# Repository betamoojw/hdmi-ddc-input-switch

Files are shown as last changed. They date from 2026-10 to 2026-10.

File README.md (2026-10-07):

# HDMI-DDC Input Switch

A small desk box with mechanical keys that switches your monitor's input in one press.
It plugs into a spare HDMI port on the monitor and sends the monitor's own "change input"
command over DDC/CI, so it works with whatever is on the other inputs: a PC on
DisplayPort, a laptop on USB-C, a console on HDMI. Nothing to install on any computer.

**Project page: <https://jeyeager65.github.io/hdmi-ddc-input-switch/>**: build guide,
configurator and firmware installer.

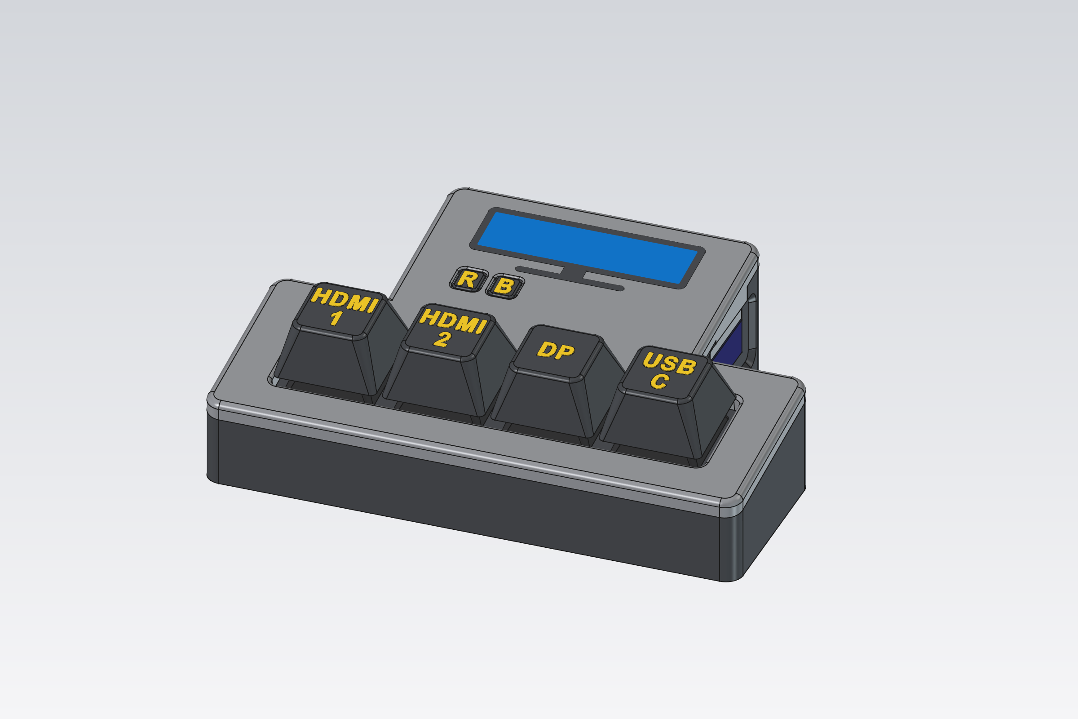
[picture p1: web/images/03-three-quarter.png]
The switch


- **[Adafruit Feather RP2040 DVI](https://www.adafruit.com/product/5710)** inside; keys are
  standard MX switches (built with [Kailh Tactile Brown](https://www.adafruit.com/product/4954)).
- **Any DDC/CI monitor** via presets. Includes LG UltraGear, which needs LG's
  proprietary command (tested on the 45GR75DC-B), and the standard MCCS command.
- **Info screen:** pressing the key for the switch's own HDMI port shows the current
  setup on the monitor.
- **Set up in the browser:** a web page (Chrome/Edge, Web Serial) installs firmware
  and configures the keys. Settings live on the switch.
- **3D-printed case** designed to print without supports, with multi-colour inlays.

## Build it

Everything for building and using it is on the
[project page](https://jeyeager65.github.io/hdmi-ddc-input-switch/): **parts list, print
files, wiring, assembly, monitor setup, configuration, firmware install and
troubleshooting**. You can also run the page locally (below). Firmware is attached to
each [release](https://github.com/jeyeager65/hdmi-ddc-input-switch/releases) too.

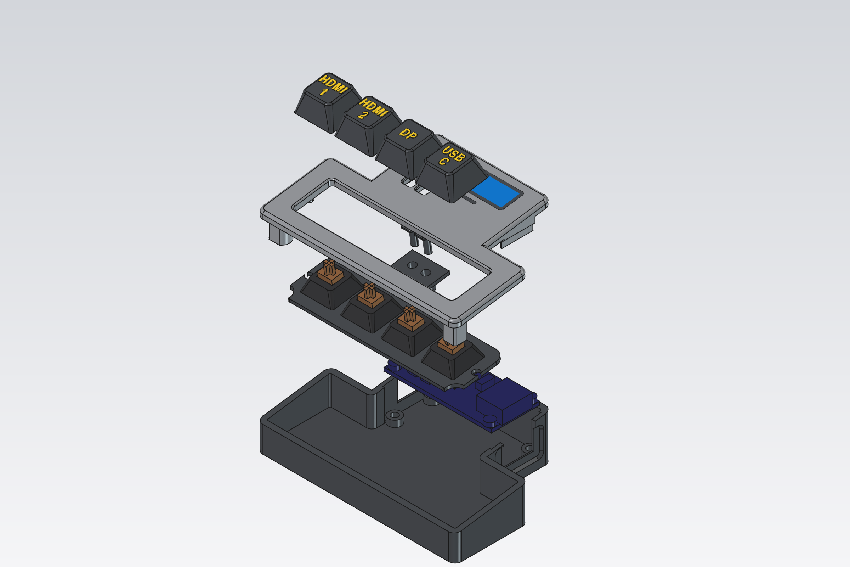
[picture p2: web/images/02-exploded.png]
Exploded view


## Repository layout

| Path | What |
|---|---|
| `src/` | Firmware (Arduino, earlephilhower RP2040 core): `config` (flash settings), `ddc` (DDC/CI), `buttons`, `protocol` (JSON over USB serial), `screen` (PicoDVI info screen), `app` |
| `web/` | The project page: guide, configurator and installer (`index.html`), monitor presets (`presets.json`), images |
| `case/` | Parametric FreeCAD scripts for the case (`case.py`), keycaps (`keycaps.py`), test prints (`coupon.py`), assembly preview (`assembly.py`), build-step scenes (`steps.py`), GUI preview colours (`show.py`), guide pictures (`render.py`) |
| `case/export/` | Print-ready STL / 3MF files |
| `tools/version.py` | Stamps the firmware version from the git tag |
| `tools/gfxfont.py` | Makes the info screen's bitmap fonts (see `src/fonts/`) |
| `tools/screenshot.py` | Saves the info screen as a PNG over USB serial (`python tools/screenshot.py COM11 out.png`) |
| `.github/workflows/firmware.yml` | CI: build; on tags, release + publish the page |
| `PLAN.md` | Design decisions, protocol, progress and test checklist |

## Firmware

Built with [PlatformIO](https://platformio.org/). The platform, core and libraries are
pinned in `platformio.ini`.

```sh
pio run -e feather_dvi          # build → .pio/build/feather_dvi/firmware.uf2
```

To flash, put the board in install mode (hold BOOT, tap RESET, or use the page's
Install tab) and copy `firmware.uf2` to the `RPI-RP2` drive. On Windows, `pio run -t
upload` needs a Zadig driver for picotool; copying the file doesn't.

Serial at 115200: one JSON object per line (`{"cmd":"version|get|set|save|send|raw|scan|reset|reboot|bootloader|screenshot"}`),
plus `1`–`8` / `s` / `?` shortcuts for bench testing. See `src/protocol.h` and `PLAN.md`.

## Web page, locally

Web Serial needs https or `localhost`:

```sh
cp .pio/build/feather_dvi/firmware.uf2 web/      # optional: for the Install tab
mkdir -p web/print && cp case/export/*.{stl,3mf} web/print/   # optional: guide downloads
python -m http.server 8000 -d web                # then open http://localhost:8000
```

## Case

The case is generated by Python scripts run inside FreeCAD 1.x, all dimensions as
parameters at the top of each file. Headless:

```sh
freecadcmd case/case.py        # tray, lid (+ inlays), switch plate, R/B buttons → case/export/
freecadcmd case/keycaps.py     # keycaps + stem-fit test
freecadcmd case/assembly.py    # assembly and exploded preview → case/build/
freecadcmd case/steps.py       # build-step scenes → case/build/
```

Then, in the FreeCAD GUI's Python console, `case/render.py` renders the README and guide
pictures into `web/images/`.

Board geometry comes from Adafruit's published PCB files; connector heights were
measured. The scripts check for collisions and overhangs as they go.

Things you may want to change (top of each file):

- `case.py`: `USB_PLUG` / `HDMI_PLUG`, your cables' plug housing sizes (they set the
  port recesses and the case height); `NUM_KEYS`; `TILT_DEG`; `LID_ART`.
- `keycaps.py`: `LEGENDS`, the text on each key, left to right (`
` for two lines).
- Print settings that the geometry assumes: 0.2 mm layers (inlays are 0.6 mm deep;
  `SACRIFICIAL_LAYER` bridges the screw holes), 0.4 mm nozzle.

## Adding a monitor

Find your monitor's values with the configurator's **Try** button, then add an entry to
`web/presets.json`:

```json
{ "id": "brand-model", "name": "Brand Model", "vcp": 96, "src": 81,
  "inputs": [{ "name": "DP", "value": 15 }, { "name": "HDMI 1", "value": 17 }],
  "notes": "What you tested it on." }
```

`vcp`/`src` are the input-select VCP code and DDC/CI source address (standard: `0x60`
from `0x51`). Pull requests welcome.

## Releases

Pushing a tag like `v1.0.0` builds the firmware, attaches it to a GitHub Release, and
publishes the project page (with that firmware and the print files) to GitHub Pages.
One-time setup: **Settings → Pages → Source: GitHub Actions**.

## License

MIT, see [LICENSE](LICENSE). That covers the firmware, the web page and the case and
keycap designs. The info screen's fonts are Noto Sans under the SIL Open Font
License (see `src/fonts/README.md`).

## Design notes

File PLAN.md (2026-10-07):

# hdmi-ddc-input-switch — Implementation Plan

Companion to [hdmi-ddc-input-switch-brief.md](hdmi-ddc-input-switch-brief.md). Where this plan and the brief disagree, **this plan wins** (see Decisions).

## Decisions

| # | Decision | Replaces in brief |
|---|---|---|
| D1 | **Runtime configuration**, stored in flash, edited from a web configurator over Web Serial. One firmware build for everyone. | Compile-time profile selection |
| D2 | Monitor "profiles" become **presets** in `web/presets.json`. Adding a monitor = adding a preset. | Profiles in C++ |
| D3 | Invalid config (a button pointing at an input that doesn't exist, bad pin) is **rejected**: the firmware refuses it and the web page blocks the save. | `static_assert` |
| D4 | **Always output video** on the Feather's HDMI port: a simple text info screen. Compile flag exists only to turn it *off* for debugging. | Conditional DVI keep-alive, "status page out of scope" |
| D5 | No special "Info" button. The info screen is just the input the Feather is plugged into (e.g. HDMI 2); the user maps a normal button to it and labels the keycap. No toggle-back. | — |
| D6 | **Button count is configurable** (1–8 in firmware, limited by free pins); the case is parametric in the same count. | Fixed 2–4 |
| D6a | Buttons have an **action**: switch input, send an arbitrary VCP set command (e.g. a brightness preset), or none. Lets a button whose input is unused (HDMI 1 today) do something else. The onboard **BOOT button is readable as GPIO7** (isolated by diode D3 per the schematic), so it can be an extra configurable button, reachable through a pinhole in the lid (e.g. long-press = factory reset). RESET (SW1) is hardwired to RUN and can't be repurposed. | "Brightness/contrast out of scope" (only as a generic VCP action; no dedicated UI) |
| D7 | No unit-test environment. Verification is on hardware via the serial protocol. | — |
| D8 | Install via **UF2 + web page** (1200-baud touch → BOOTSEL drive → save `.uf2`). No WebUSB/PICOBOOT for v1 (Windows driver issue). | — |
| D9 | Case designed in **FreeCAD 1.1** as a parametric Python script, driven via the `freecad` MCP server (`.mcp.json`). | — |

## Architecture

### Repository layout

```
platformio.ini
src/
  main.cpp          setup/loop: buttons, serial, screen refresh
  config.h/.cpp     Config struct, defaults, validate(), load/save (EEPROM emu + CRC)
  ddc.h/.cpp        buildPacket(), ddcSend(), scanBus()   (transport kept separate — see Future)
  buttons.h/.cpp    debounce, edge detect
  protocol.h/.cpp   JSON-lines + single-char bench commands
  screen.h/.cpp     PicoDVI text-mode info screen (#ifndef DISABLE_VIDEO)
web/
  index.html        Install + Configure tabs (static, GitHub Pages)
  presets.json      monitor presets
case/
  case.py           parametric FreeCAD script (source of truth)
  export/           generated STL/3MF (built from case.py)
.github/workflows/
  build.yml         build .uf2 on push; attach to Release on tag
  pages.yml         deploy web/ (+ latest .uf2) to GitHub Pages
```

### Config model (firmware)

```cpp
struct InputDef  { char name[12]; uint8_t value; };
enum class Action : uint8_t { None, Input, Vcp };
struct ButtonDef {
  uint8_t pin;
  Action  action;
  uint8_t inputIndex;             // Action::Input
  uint8_t vcpCode, vcpSrc;        // Action::Vcp — any VCP set, e.g. a brightness preset (0x10) or picture mode
  uint16_t vcpValue;
};

struct Config {
  uint16_t  magic, schema;        // schema bumps on layout change → defaults
  char      presetName[24];
  uint8_t   vcpCode;              // 0xF4 LG / 0x60 MCCS
  uint8_t   sourceAddr;           // 0x50 LG / 0x51 MCCS
  uint8_t   numInputs;  InputDef  inputs[8];
  uint8_t   selfInput;            // index of the input the Feather is plugged into (0xFF = unknown)
  uint8_t   numButtons; ButtonDef buttons[8];
  uint32_t  crc;
};
```

- **Defaults** (empty/corrupt flash or schema mismatch): LG UltraGear; inputs DP `0xD0`, USB-C `0xD1`, HDMI 1 `0x90`, HDMI 2 `0x91`; self = HDMI 2; buttons left to right (as on the printed keycaps) A0→HDMI 1, A1→HDMI 2, A2→DP, A3→USB-C.
- **validate()**: `numInputs ≤ 8`, `numButtons ≤ 8`, each `Action::Input` button's `inputIndex < numInputs`, each pin in the allowed list and unique, names non-empty.
- **Allowed pins** (from schematic): A0–A3 (GPIO26–29), D24, D25, D5, D6, D9, D10, D11, D12, D13 (has red LED + resistor; usable with pull-up, LED glows faintly), MISO/MOSI/SCK, RX/TX, and BOOT (GPIO7). Excluded: SDA/SCL (GPIO2/3, DDC), GPIO4 (NeoPixel), GPIO16–23 (DVI).
- **Storage**: earlephilhower `EEPROM` emulation (one flash sector). A flash write stalls both cores, so video will glitch on save — accepted, documented.
- **Factory reset**: hold the first two buttons at power-up (or `{"cmd":"reset"}`).
- Packet + checksum are generic: `[src, 0x84, 0x03, vcp, 0x00, value, xor(0x6E, …)]`. Known-good: LG DP → checksum `0x9D`; MCCS DP1 `0x0F` → `0xD7`.

### Serial protocol (115200, newline-terminated)

Lines starting with `{` are JSON (ArduinoJson); otherwise single-char bench commands.

| Request | Response |
|---|---|
| `{"cmd":"version"}` | `{"fw":"1.0.0","schema":1,"board":"feather_dvi"}` |
| `{"cmd":"get"}` | full config as JSON (`pin` as Feather labels like `"A0"`, `self` = input index or -1) |
| `{"cmd":"set","config":{…}}` | `{"ok":true}` or `{"ok":false,"error":"button 2: input 5 out of range"}` — applies to RAM only |
| `{"cmd":"save"}` | writes flash |
| `{"cmd":"send","input":2}` | `{"ok":true,"ack":true}` |
| `{"cmd":"raw","vcp":244,"src":80,"value":208}` | ack — for discovering values on new monitors |
| `{"cmd":"scan"}` | `{"devices":[55,80]}` |
| `{"cmd":"reset"}` / `{"cmd":"reboot"}` / `{"cmd":"bootloader"}` | |
| `1`–`8` `s` `?` | bench shortcuts: send input slot 1–8, scan, help (human-readable) |

Unsolicited events (button presses, boot scan) are emitted as `{"event":…}` lines so the web page can show live activity.

### Info screen

PicoDVI 1-bit graphics, 640×480 (`DVIGFX1`, `DVI_RES_640x480p60`), drawn with Adafruit GFX and Noto Sans bitmap fonts: title with a version pill, framed Keys / Monitor / Tips panels (a Last command panel would always show the switch's own input), the switch's own input highlighted, setup address and uptime in the footer (was 80-column text until 2026-10-06). Video only while the screen is in use (see Progress). Runs on core 1. Call `Wire.setClock(50000)` **after** video starts (PicoDVI changes the system clock).

```
 HDMI-DDC INPUT SWITCH  v1.0.0          Preset: LG UltraGear (VCP F4 / src 50)
 You are viewing HDMI 2 - the switch's own port.

 Buttons:  [1] DP   [2] USB-C   [3] HDMI 1   [4] HDMI 2
 DDC:      0x37 OK   EDID 0x50 OK
 Last:     USB-C (0xD1) ACK   12s ago
 Configure: https://jeyeager65.github.io/hdmi-ddc-input-switch/
```

### Web page

Single static page, Chrome/Edge only (Web Serial). No build step.

- **Install tab**: pick port → open at 1200 baud and close (core reboots to BOOTSEL) → fetch latest `.uf2` → `showSaveFilePicker` onto the `RPI-RP2` drive. Fallback text: hold BOOT, tap RESET, drag the file.
- **Configure tab**: connect → `version` (warn on schema mismatch) → `get` → form:
  - preset dropdown (from `presets.json`) or Custom: VCP code, source address
  - input table: name, value, **Try** button (`send`/`raw`), "this is the switch's own port" radio
  - button table: pin dropdown (allowed pins only), input dropdown; add/remove rows
  - client-side validation mirrors firmware → **Save** (`set` then `save`)
  - live event log
- **presets.json** entry: `{ "id", "name", "vcp", "src", "inputs":[{"name","value"}], "notes" }`. Ship `lg-ultragear` and `mccs-standard` (DP1 0x0F, DP2 0x10, HDMI1 0x11, HDMI2 0x12; USB-C omitted — vendor-specific, e.g. Dell 0x1B).

### Case (FreeCAD)

**Decided (2026-10-03):** board centred behind the key row, fully inside the walls; the back section's side walls are thinned to 1.6 mm and the overhanging receptacle shells poke into tight holes (+0.25 mm), so plugs seat within ~1 mm of full insertion; lid is a flat plate mounted at 8° (keys centred in the front section); prints without supports (one-layer bridge capping each screw counterbore, no foot recesses — bumpers stick to the flat bottom); heat-set inserts (M2.5 for the Feather, M3 for the lid: 2 screws up through the floor at the front, 2 through the back wall); switches in a separate flat plate glued under a window in the lid (keytops 10.4 mm above the lid); RST/BOOT are real buttons: printed PLA plunger pins (rounded rectangles 4.4 × 3.6 mm with inlaid R / B, flush with the lid) resting on the board's buttons with a level-cut tip, guided by a sleeve on the switch plate's tab and trapped by a collar between the lid and that tab (0.4 mm press travel, 0.2 mm lift); no RST/BOOT text on the lid; lid art: an ultrawide monitor inlay (`LID_ART`); 4 keys; multi-colour printed keycaps.

Built: `case/coupon.py` (switch-fit coupon), `case/case.py` (tray + lid + switch plate, 94 × 65.5 mm, 14.3 mm high at the front / 23.5 mm at the back, 4 keys; board fully in the back section; tight port holes with a shallow recess for the plug housing; slots open at the top so the board drops in, closed by lid tabs. Changed after the first tray print trapped the board and blocked the plugs, 2026-10-04. R/B pins: 4.4 × 5.0 mm tops, letters styled like the keycap legends (Arial Narrow Bold 3.76 mm, strokes +0.12 mm), looser tip guides), `case/assembly.py` (preview with switches and keycaps, plus fit checks), shared helpers in `case/cadlib.py`. Board geometry is from Adafruit's Eagle files; connector heights, overhangs and RST/BOOT button height measured on the real board (2026-10-03). Switch cutout 14.0 mm and keycap stem cross 1.30 mm confirmed by test prints.

Keycaps: `case/keycaps.py` — low flat-top MX caps printed face-down with a flush two-colour legend (0.6 mm inlay, separate 3MF part), Arial Narrow Bold at one shared size; the top sits just above the stem and a deep skirt hides the switch and stops travel at 3 mm (Browns actuate at ~2 mm). Order left to right: HDMI 1, HDMI 2, DP, USB-C. Also a stem-fit test strip (cross widths 1.20–1.40 mm).

Colours (all PLA, "stealth"): tray black; lid gray with a black monitor frame and blue screen inlay; keycaps black with yellow legends; R/B buttons black with yellow letters; switch plate black (hidden). Filament is assigned per part in Bambu Studio.

Hardware: 4× M2.5×4×3.5 OD heat-set insert + 4× M2.5×6 screw (board, 3 mm standoffs so solder joints underneath need no trimming); 4× M3×4×5 OD heat-set insert (4.2 mm hole) + 4× M3×6 button-head screw (lid: 2 up through the floor at the front, 2 horizontally through the back wall); 4× adhesive bumper (any size, clear of the front screw holes); superglue for the switch plate (drop the two button pins in first; the plate's tab traps them).

Original parameter notes:

- `NUM_KEYS`, `KEY_PITCH = 19.05`, `SWITCH_CUTOUT = 14.0` (+ print tolerance), `PLATE_T = 1.5`
- Feather footprint 50.8 × 22.8 mm; connector positions from Adafruit's PCB files / STEP (don't guess)
- Openings for HDMI and USB-C; pinhole for RESET/BOOT
- Weight/feet allowance — HDMI cable stiffness will drag a light box
- Assembly: heat-set inserts (M2/M3) vs snap-fit — decide in Phase 8
- Optional: parametric keycap with embossed/debossed legend (e.g. "HDMI 2")
- First print a **switch-plate test coupon** to tune cutout tolerance

Workflow: Claude edits `case.py` → runs it via the MCP → reviews screenshots → exports STL/3MF to `case/export/`.

## Phases

| # | Phase | Done when |
|---|---|---|
| 0 | `git init`, `.gitignore`, `platformio.ini`; confirm board resolves; confirm `Wire` (not `Wire1`) reaches the DDC lines; confirm DVI + allowed pin list from schematic | Blink + serial echo uploads |
| 1 | Port reference code as-is (LG, one file) | Boot scan shows `0x37` and `0x50`; `d`/`c`/`1` switch the monitor |
| 2 | Add video + info screen | Picture on HDMI 2; DDC still ACKs; inactive-input switching works (bench test from brief) |
| 3 | Config model, flash storage, validation, JSON protocol | `get`/`set`/`save` round-trip survives reboot; bad config rejected |
| 4 | Buttons from config, debounce, factory-reset combo | One switch per press, no repeat; reset combo restores defaults |
| 5 | Hardening: one retry on NACK, 50 ms inter-command gap, pin platform commit, version string from git tag | Survives monitor power cycle without Feather reset |
| 6 | CI: build `.uf2`, attach to Release on tag | Tag → Release has `hdmi-ddc-input-switch-<ver>.uf2` |
| 7 | Web page + presets + Pages deploy | Fresh board → installed and configured entirely from the page |
| 8 | Case (can run in parallel after Phase 0 dims) | Coupon fits switches; full case printed and assembled |
| 9 | README: wiring, install, configure, adding a preset, safety notes | — |

## Progress

- **2026-10-03 — Phase 0 done:** git repo, `platformio.ini` (maxgerhardt platform, earlephilhower core, `adafruit_feather_dvi` resolves), firmware builds. Upload: picotool can't reach BOOTSEL on Windows without a Zadig driver, so flash by copying `.pio/build/feather_dvi/firmware.uf2` to the RPI-RP2 drive (the web installer plan already assumes this).
- **2026-10-03 — Phase 1 done:** reference code ported (4 keys: A0 HDMI 1, A1 HDMI 2, A2 DP, A3 USB-C). On the LG 45GR75DC-B via HDMI 2: I²C scan shows 0x37 + 0x50 (plus 0x30, 0x3A, 0x49, 0x4A, 0x51, 0x54, 0x59); `Wire` on GPIO2/3 is correct; VCP 0xF4 / src 0x50 switched DP → USB-C → DP with ACKs. **DDC is accepted on HDMI 2 while another input is displayed — no video keep-alive needed for switching** (video stays for the info screen, D4).

- **2026-10-03 — Phase 2 done:** PicoDVI `DVItext1` (80x30 text at 640x240p60) shows the info screen on HDMI 2; the LG accepts the mode. Video starts first, then `Wire.setClock(50000)`; DDC still ACKs. Flashing without buttons: open the serial port at 1200 baud (core reboots to BOOTSEL), then copy the `.uf2`. Still to check on the desk: Auto Input Switch off, and monitor standby with the Feather's video always on.

- **2026-10-03 — Phase 3 done (fw 0.3.0):** `config.*` (flash via EEPROM emulation, magic + schema + CRC, LG defaults, validation, allowed-pin list incl. BOOT/GPIO7), `ddc.*` (generic 16-bit VCP set), `app.*` (status + actions), `buttons.*` (debounce, keys 1+2 at power-up = factory reset), `protocol.*` (JSON lines via ArduinoJson 7 + bench keys), `screen.*` (reads config). Tested on the board: version/get/set/save/reset, validation errors, `id` echo; saved config survives a reflash.

- **2026-10-03 — Phase 7 done (local):** `web/index.html` + `web/presets.json`. Configure tab (connect by Adafruit USB VID, presets, inputs with Try + auto switch-back to "This computer" after 10 s, keys, client-side validation mirroring the firmware, save/undo, scan, factory reset, restart, live activity log) and Install tab (1200-baud reboot to RPI-RP2, then save `firmware.uf2` onto the drive via the File System Access API, or a local .uf2). Tested on the board in Chrome via `python -m http.server`. Deploying it is Phase 6.

- **2026-10-03 — Phase 5 done:** platform pinned to maxgerhardt/platform-raspberrypi `5d4561a` (→ arduino-pico `fd65f6d`, framework 1.60100.0); libraries pinned (PicoDVI 1.3.2, Adafruit GFX 1.12.6, ArduinoJson 7.4.3); `tools/version.py` stamps `FW_VERSION` (env var from CI → `git describe` → `dev`); DDC sends retry once after 150 ms on NACK. A 0.4.0 build was installed through the web page's Install tab and reported its version correctly.

- **2026-10-03 — Phase 6 written (runs once pushed):** `.github/workflows/firmware.yml` — `build` on every push/PR (version from tag or `git describe`, `.uf2` artifact); on `v*` tags `release` (GitHub Release with `hdmi-ddc-input-switch-<ver>.uf2`) and `pages` (deploys `web/` + that firmware as `firmware.uf2`). Needs Settings → Pages → Source: GitHub Actions.

- **2026-10-03 — Phase 9 done:** the build/use guide lives in the web page's **Guide** tab (parts, print files with download links, wiring, assembly, monitor setup, using it, adding a monitor, troubleshooting); the page opens on the Guide for new visitors and on Configure after a switch has been connected. `README.md` is the repo front page (overview, layout, building firmware/page/case, presets, releases). Renders moved to `web/images/`; CI publishes `web/` + images + `case/export` print files + firmware.

- **2026-10-05 — Phase 8 (case) printed and assembled; keys wired and working.** Second case print (board in the back section, tight port holes with plug recesses and lid tabs). Keys wired with 22 AWG stranded silicone wire: one ground wire window-stripped along the same pin of every switch (pins too short for two wires), one signal wire per key to A0–A3, soldered from the board's underside. Wiring pictures in the Guide (`web/images/wiring-switches.svg`).

- **2026-10-06 — Video on demand:** with the Feather's video always on, the LG jumped to HDMI 2 whenever the active input slept. Now `screenVideo()` detaches the DVI pins (GPIO 16–23) so the port is dark; the switch's own key turns the picture on (300 ms before the DDC command), any other input turns it off, and it times out after 5 minutes. PicoDVI keeps running; DDC is unaffected.

- **2026-10-06 — Info screen restyled:** 640×480 1-bit graphics with framed panels instead of the 8×8 text mode. Fonts: Noto Sans (OFL; best of ten open fonts in a 1-bit side-by-side) rendered to GFX bitmap fonts at 28/17/15/14 px by `tools/gfxfont.py` (`src/fonts/`); Adafruit's FreeSans looked too big once the monitor scaled 480 lines to 1440. New serial command `screenshot` sends the framebuffer as hex rows; `tools/screenshot.py COM11 out.png` saves it (layout checks, docs).

## Hardware test checklist

- [x] Boot scan shows `0x37` and `0x50`
- [ ] Switch DP → USB-C → HDMI 1 → HDMI 2 from each button and serial
- [x] Switching works while the monitor displays a *different* input
- [x] Monitor accepts the text-mode video timing
- [x] Monitor does not jump to HDMI 2 when the PC sleeps (2026-10-06, with on-demand video; Auto Input Switch setting no longer matters)
- [x] Monitor still enters standby when the active input goes idle (HDMI 2 is dark unless the info screen is in use)
- [ ] Monitor power cycle → next button press still works
- [ ] Save config → brief video glitch only → config persists across power cycle
- [ ] Factory-reset combo works

## Risks

| Risk | Mitigation |
|---|---|
| Monitor ignores DDC on an inactive input | Always-on video (D4) makes HDMI 2 a live source |
| LG auto-input grabs HDMI 2 | Seen 2026-10-06. Fixed in firmware: video only while the info screen is in use (see Progress) |
| Monitor never sleeps with a live source | Test; add video-blank timeout if needed |
| Text-mode timing rejected | Fall back to 640×480 1-bit |
| PicoDVI clock change breaks I²C timing | Re-apply `Wire.setClock` after `display.begin()` |
| Flash write stalls video | Accept; save is rare and user-initiated |
| Web Serial is Chromium-only | Document; manual UF2 fallback |
| STEMMA QT shares the DDC bus | Case should cover/block the port; README warning |

## Future: inline variant (not planned for v1)

Idea: sit **between a source and the monitor** on an input that's already in use, instead of occupying a spare HDMI port.

- **HDMI only, realistically.** HDMI exposes DDC as plain I²C on dedicated pins, so a passthrough board can carry the TMDS pairs straight through and tap SDA/SCL/HPD/+5V. DisplayPort carries DDC over the AUX channel (differential, Manchester-coded) and USB-C carries DP inside alt mode — both need an AUX transceiver at minimum and are much harder. The current setup (DP + USB-C sources) wouldn't benefit.
- **Signal integrity**: TMDS passthrough at HDMI 2.1 rates (up to 48 Gbps FRL) needs a carefully designed PCB with impedance-controlled, length-matched pairs; HDMI 2.0 rates are more forgiving. Off-the-shelf "DDC breakout"/EDID-emulator adapters might serve as a prototype.
- **Shared bus**: the source's GPU is also an I²C master on DDC (EDID reads on hotplug, any DDC/CI software). Inject only when the bus is idle and rely on RP2040 multi-master arbitration-loss detection, or use an I²C bus switch to briefly isolate the source side.
- **Upside**: monitors that only listen to DDC on the *active* input would work.
- **Downside**: no info screen (the source owns the video link).
- **Design hook for now**: keep `ddc.cpp`'s transport behind a small interface (`ddcSend(packet)`) so an inline variant can reuse config, protocol, buttons, and web page unchanged.

## Open items

- Exact allowed-pin list (Phase 0, from schematic)
- Case assembly method and keycap profile (Phase 8)
- Platform commit to pin (Phase 5)

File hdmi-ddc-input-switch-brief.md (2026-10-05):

# hdmi-ddc-input-switch — Project Brief

## Goal

Firmware for a small desk box with physical mechanical-key buttons that switches a monitor's input. The box is an **Adafruit Feather RP2040 DVI** connected to one of the monitor's HDMI ports; it sends DDC/CI commands over that port's I²C (DDC) lines.

The project should be **generic**, so it works with any DDC/CI monitor through per-monitor profiles. The first target, and the only one tested so far, is the **LG 45GR75DC-B UltraGear**, which uses a nonstandard LG method (see Protocol).

Keep it simple and appliance-like: instant-on, no network, no status LEDs.

## Hardware

- **Board:** Adafruit Feather RP2040 DVI (product 5710). The HDMI connector's DDC SDA/SCL are wired to the Feather's main SDA/SCL through an onboard level shifter, so `Wire` talks to the monitor directly.
- **Connection:** Feather HDMI → monitor **HDMI 2** (dedicated control port). Monitor inputs in use: DisplayPort and USB-C. HDMI 1 is free for future use.
- **Buttons:** Kailh Brown (MX-compatible) switches, each wired between a GPIO pin and GND. Use internal pull-ups, no external resistors.
- **Power:** USB-C.
- **Do not** attach anything to the STEMMA QT port. It shares the I²C bus with the monitor's DDC line.

## Protocol

### Standard DDC/CI input switching (most monitors)

- VCP code **0x60** (Input Source), source address **0x51**
- Packet bytes: `0x51, 0x84, 0x03, 0x60, 0x00, <value>, <checksum>`
- Common MCCS values: `0x0F` DP1, `0x10` DP2, `0x11` HDMI1, `0x12` HDMI2. Vendors vary, so values belong in the profile.

### Input switching (LG proprietary)

LG ignores the standard VCP 0x60 input select. It uses proprietary **VCP 0xF4** sent with **source address 0x50** (not the standard 0x51). This has been confirmed working on this monitor using deskmux on Windows.

- I²C 7-bit address: `0x37` (DDC/CI, 0x6E write address)
- Packet bytes: `0x50, 0x84, 0x03, 0xF4, 0x00, <value>, <checksum>`
- Checksum: XOR of `0x6E` and every preceding packet byte
- Wait ~50 ms between DDC commands
- The monitor does **not** report the current input via this sidechannel. Don't attempt read-back.

| Input | Value  |
|---|---|
| DisplayPort | `0xD0` |
| USB-C | `0xD1` |
| HDMI 1 | `0x90` |
| HDMI 2 | `0x91` (the Feather's own port) |

## Requirements

0. **Monitor profiles:** a profile struct holds the VCP code, source address, and a named table of input values. Ship two profiles, `LG_ULTRAGEAR` (0xF4 / 0x50) and `MCCS_STANDARD` (0x60 / 0x51), selected at compile time (e.g. a build flag in `platformio.ini`). Adding a monitor should mean adding a profile, never changing the core logic. Document how to add one in the README.
1. **Button handling:** a configurable array maps each button pin to an input value. Default mapping:
   - `A0` → DisplayPort
   - `A1` → USB-C
   - `A2` → HDMI 1
   - The button count must be easy to change (2–4 buttons) by editing one array.
2. **Fire on press**, with ~30 ms debounce. No repeat while held.
3. **Serial test interface** at 115200 baud for bench testing without buttons:
   - `d` = DP, `c` = USB-C, `1` = HDMI 1, `2` = HDMI 2, `s` = I²C bus scan
   - Log each send with ACK/NACK from `Wire.endTransmission()`
4. **Boot diagnostic:** I²C scan on startup. A connected monitor should show `0x37` (DDC/CI) and `0x50` (EDID).
5. I²C clock 50 kHz (DDC is slow).

## Build setup (PlatformIO)

```ini
[env:feather_dvi]
platform = https://github.com/maxgerhardt/platform-raspberrypi.git
board = adafruit_feather_dvi
framework = arduino
board_build.core = earlephilhower
monitor_speed = 115200
```

- Use the maxgerhardt platform fork (the official `raspberrypi` platform only ships Arduino-Mbed). Pin it to a specific commit once the build works.
- If `adafruit_feather_dvi` doesn't resolve, check `pio boards rp2040`.
- Source in `src/main.cpp` with `#include <Arduino.h>`.
- First upload: hold BOOT, tap RESET. Later uploads auto-reset.

## Known unknown — video fallback (conditional)

It's unconfirmed whether the monitor accepts DDC commands on an HDMI input that isn't currently displayed. Bench test: Feather on HDMI 2, monitor showing DP, send `1`, and check whether it switches to HDMI 1.

**If it doesn't work**, add a fallback: have the Feather output a solid black DVI signal (Adafruit's PicoDVI fork, 320x240 framebuffer) so the monitor sees a live source on HDMI 2. Notes:
- DVI generation uses one full core, both PIOs, and ~150K SRAM. Keep button/DDC logic on the other core or in the main loop accordingly.
- I²C is hardware, separate from the PIOs, so DDC should still work alongside video.
- Make the fallback a compile-time flag (e.g. `#define ENABLE_DVI_KEEPALIVE`) so both modes can be tested.

Don't implement this unless the bench test shows it's needed, or implement it behind the flag, defaulted off.

## Out of scope

- Wi-Fi/network control
- Status LEDs / NeoPixel
- Brightness, contrast, volume controls
- A status-page display

## Reference implementation (starting point — LG-specific, refactor into profiles)

```cpp
#include <Arduino.h>
#include <Wire.h>

const uint8_t BTN_PINS[]   = {A0, A1, A2};
const uint8_t INPUT_CODE[] = {0xD0, 0xD1, 0x90};   // DP, USB-C, HDMI1
const char*   INPUT_NAME[] = {"DP", "USB-C", "HDMI1"};
const int     NUM_BTNS     = sizeof(BTN_PINS) / sizeof(BTN_PINS[0]);

const uint8_t  DDC_ADDR    = 0x37;
const uint32_t DEBOUNCE_MS = 30;

bool     lastState[NUM_BTNS];
uint32_t lastChange[NUM_BTNS];

bool lgInput(uint8_t value) {
  uint8_t pkt[] = {0x50, 0x84, 0x03, 0xF4, 0x00, value};
  uint8_t cs = 0x6E;
  for (uint8_t b : pkt) cs ^= b;
  Wire.beginTransmission(DDC_ADDR);
  Wire.write(pkt, sizeof pkt);
  Wire.write(cs);
  uint8_t err = Wire.endTransmission();
  delay(50);
  return err == 0;
}

void sendCode(uint8_t code, const char* name) {
  bool ok = lgInput(code);
  Serial.printf("-> %s (0x%02X): %s\n", name, code, ok ? "ACK" : "NO ACK");
}

void scanBus() {
  Serial.print("I2C devices:");
  for (uint8_t a = 1; a < 127; a++) {
    Wire.beginTransmission(a);
    if (Wire.endTransmission() == 0) Serial.printf(" 0x%02X", a);
  }
  Serial.println();
}

void setup() {
  Serial.begin(115200);
  Wire.begin();
  Wire.setClock(50000);
  for (int i = 0; i < NUM_BTNS; i++) {
    pinMode(BTN_PINS[i], INPUT_PULLUP);
    lastState[i] = HIGH;
    lastChange[i] = 0;
  }
  delay(1500);
  Serial.println("Ready. d=DP c=USB-C 1=HDMI1 2=HDMI2 s=scan");
  scanBus();
}

void loop() {
  for (int i = 0; i < NUM_BTNS; i++) {
    bool s = digitalRead(BTN_PINS[i]);
    if (s != lastState[i] && millis() - lastChange[i] > DEBOUNCE_MS) {
      lastChange[i] = millis();
      lastState[i] = s;
      if (s == LOW) sendCode(INPUT_CODE[i], INPUT_NAME[i]);
    }
  }
  if (Serial.available()) {
    switch (Serial.read()) {
      case 'd': sendCode(0xD0, "DP");    break;
      case 'c': sendCode(0xD1, "USB-C"); break;
      case '1': sendCode(0x90, "HDMI1"); break;
      case '2': sendCode(0x91, "HDMI2"); break;
      case 's': scanBus();               break;
    }
  }
}
```

## Acceptance criteria

- Builds and uploads via PlatformIO.
- Boot scan shows `0x37` and `0x50` with the monitor connected.
- Serial commands and buttons switch the monitor to the mapped input.
- Changing the button mapping requires editing only the arrays at the top.

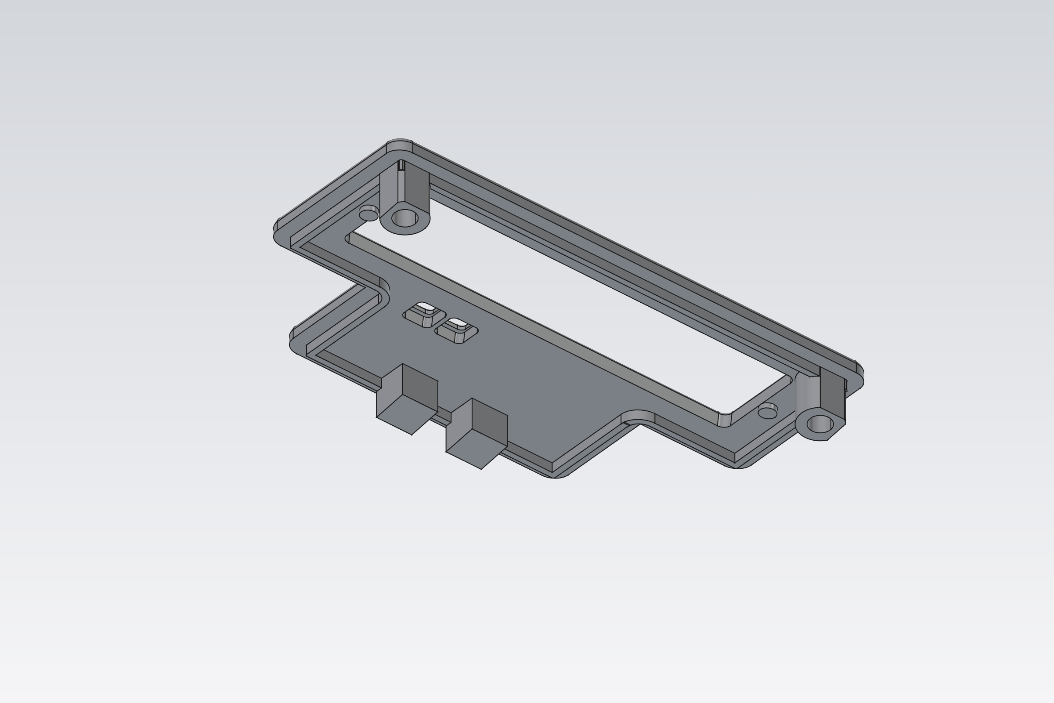
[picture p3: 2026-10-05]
web/images/04-lid-underside.png

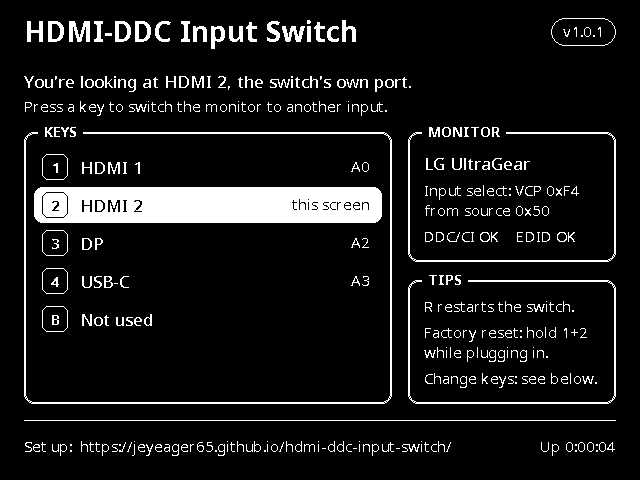
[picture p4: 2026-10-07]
web/images/info-screen.png

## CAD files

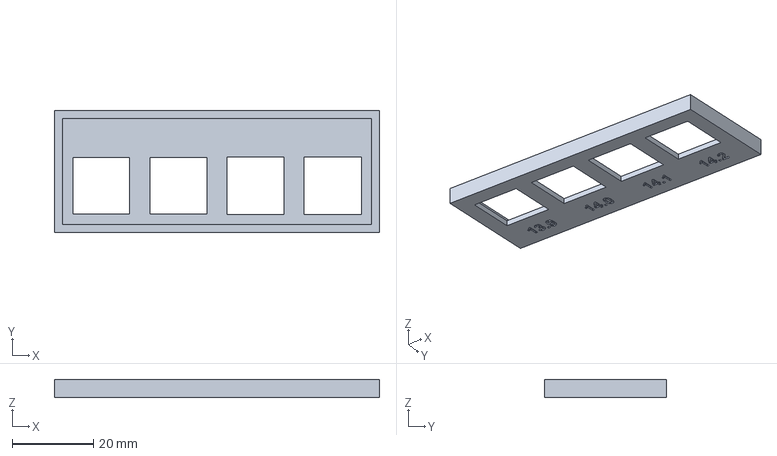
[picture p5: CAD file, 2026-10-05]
case/export/switch-coupon.3mf
80.2 x 30.1 x 4.50 mm

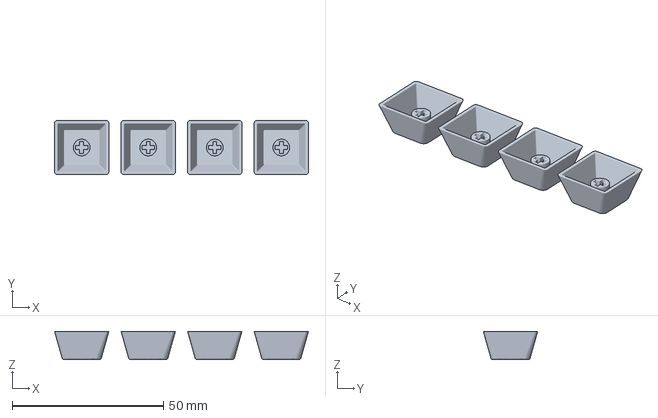
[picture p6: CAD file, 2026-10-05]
case/export/keycaps.3mf
84.0 x 18.0 x 9.40 mm

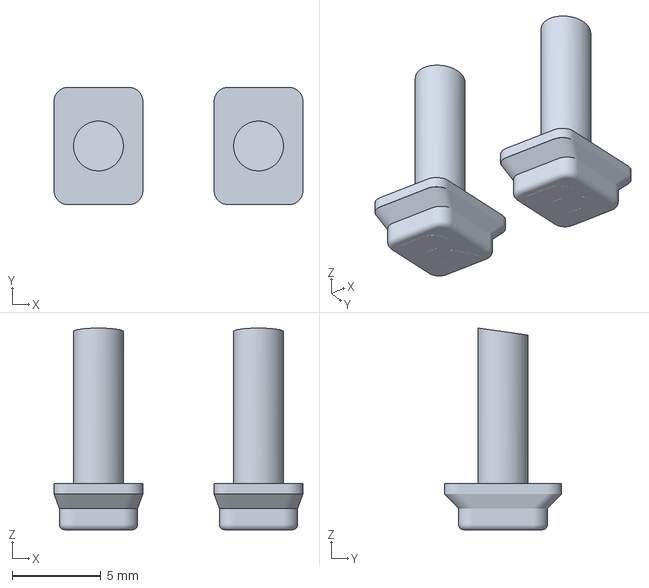
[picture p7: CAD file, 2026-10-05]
case/export/case-buttons.3mf
14.0 x 6.60 x 11.4 mm

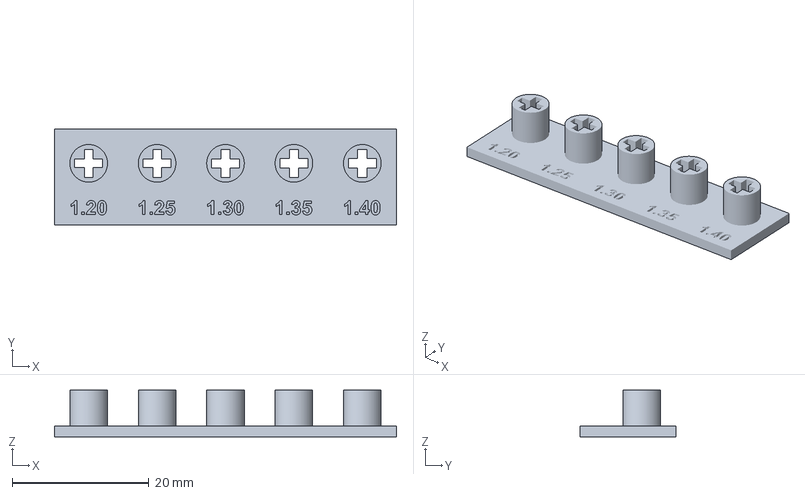
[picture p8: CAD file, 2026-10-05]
case/export/stem-fit-test.3mf
50.0 x 14.0 x 6.80 mm

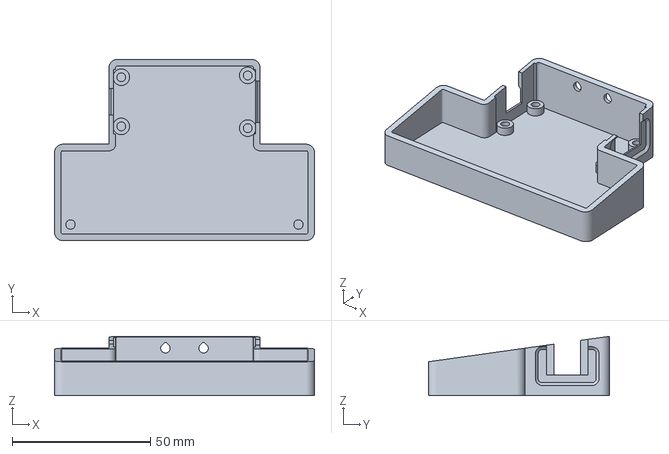
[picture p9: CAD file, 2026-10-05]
case/export/case-tray.3mf
94.0 x 65.5 x 21.5 mm

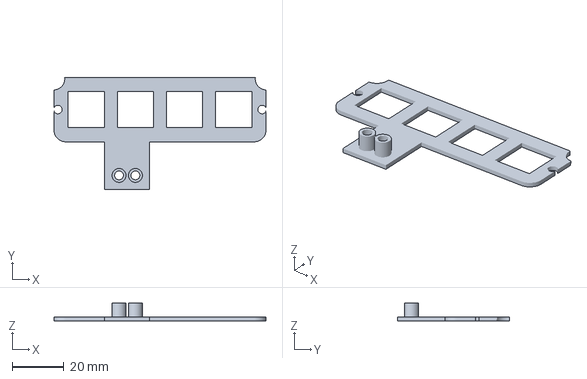
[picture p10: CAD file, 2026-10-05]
case/export/case-plate.3mf
82.2 x 43.6 x 6.94 mm

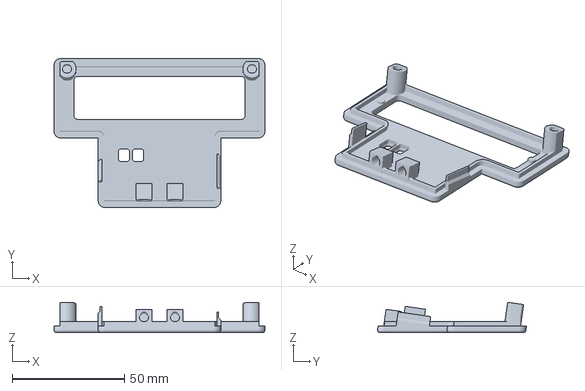
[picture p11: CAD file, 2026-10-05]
case/export/case-lid.3mf
94.0 x 66.4 x 13.5 mm

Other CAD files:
case/export/case-plate.stl
case/export/case-tray.stl
case/export/stem-fit-test.stl
case/export/switch-coupon.stl

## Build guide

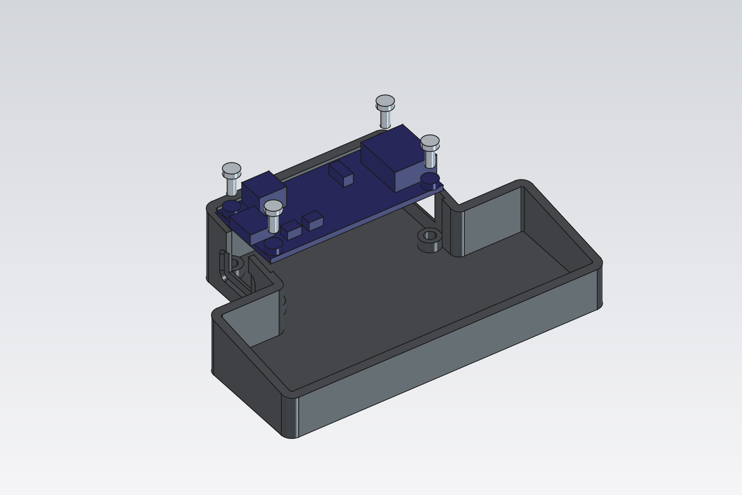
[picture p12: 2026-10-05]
web/images/step3-board.png

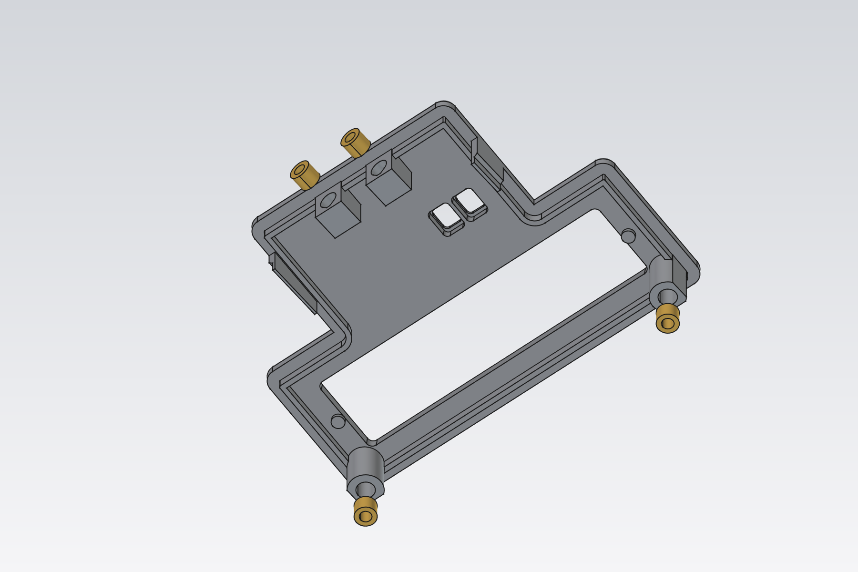
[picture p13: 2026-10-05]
web/images/step2-lid-inserts.png

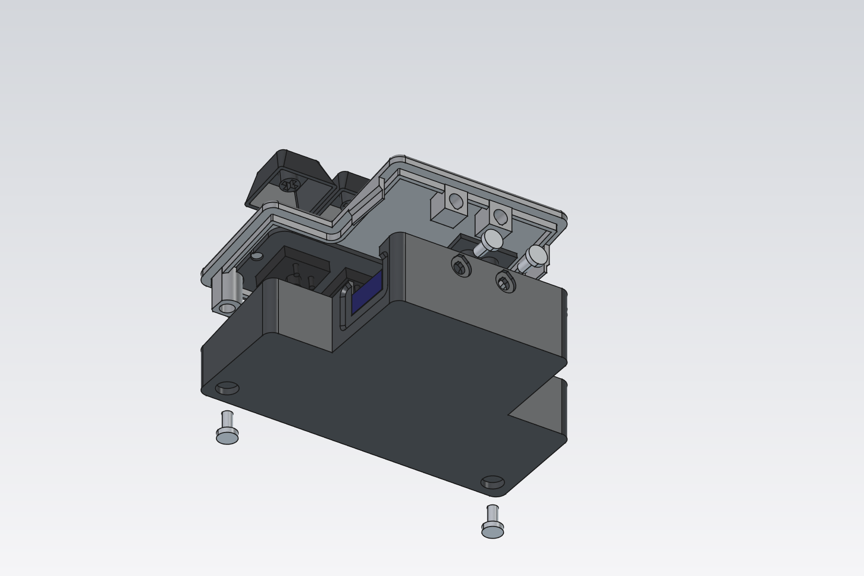
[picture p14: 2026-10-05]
web/images/step5-close-up.png

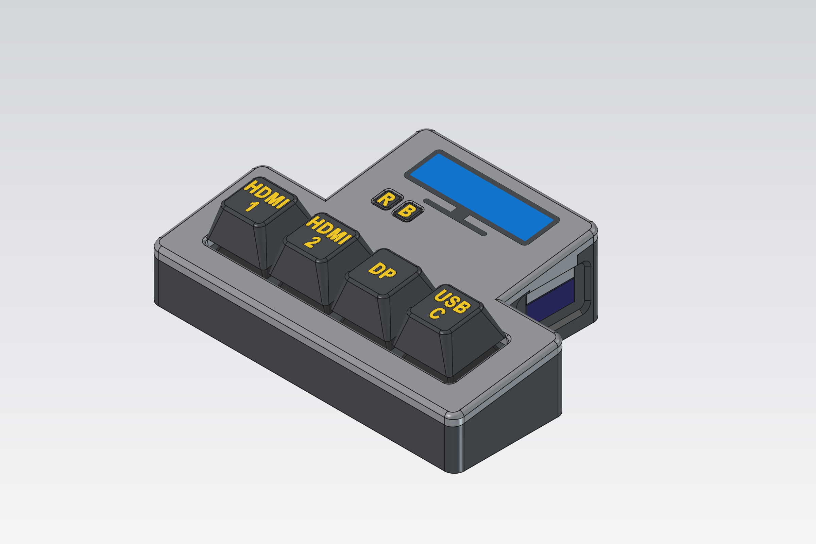
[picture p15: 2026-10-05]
web/images/01-assembled.png

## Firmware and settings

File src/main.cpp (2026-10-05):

// hdmi-ddc-input-switch — firmware for an Adafruit Feather RP2040 DVI that switches a
// monitor's input over DDC/CI from mechanical keys, with an info screen on its own
// HDMI output. Behaviour comes from the config in flash (see config.h); the web
// configurator talks to it over USB serial (see protocol.h). PLAN.md has the design.

#include <Arduino.h>
#include <Wire.h>
#include "app.h"
#include "buttons.h"
#include "config.h"
#include "protocol.h"
#include "screen.h"

static const uint32_t SERIAL_WAIT_MS = 1500;   // wait this long for a monitor, never forever

void setup() {
  // Video first: PicoDVI raises the system clock, and everything else must be set
  // up after that (the I2C clock divider in particular).
  bool video = screenBegin();

  Serial.begin(115200);
  Wire.begin();
  Wire.setClock(50000);   // DDC is slow

  bool loaded = configLoad();
  bool factoryReset = buttonsResetHeld();      // hold keys 1 + 2 while plugging in
  if (factoryReset) {
    configDefaults(config);
    configSave();
  }
  buttonsBegin();

  uint32_t t0 = millis();
  while (!Serial && millis() - t0 < SERIAL_WAIT_MS) {}
  uint8_t found[32];
  appScan(found, sizeof found);                // also draws the screen
  protocolBootEvent(loaded, factoryReset, video);
}

void loop() {
  int key = buttonsPoll();
  if (key >= 0) {
    const ButtonDef& b = config.buttons[key];
    bool ok = false;
    if (b.action == Action::Input) ok = appSendInput(b.input);
    else if (b.action == Action::Vcp) ok = appSendVcp(b.src, b.vcp, b.value, "VCP");
    if (b.action != Action::None) protocolKeyEvent(key, ok);
  }

  protocolPoll();

  static uint32_t lastTick = 0;
  if (millis() - lastTick >= 1000) {
    lastTick = millis();
    screenTick();
  }
}

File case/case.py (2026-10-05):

# Parametric enclosure for hdmi-ddc-input-switch.
#
# Two printed parts:
#   tray : floor, walls (tops follow the lid angle), Feather standoffs (M2.5 heat-set
#          inserts), port holes, screw counterbores underneath
#   lid  : flat plate mounted at TILT_DEG — MX switch cutouts, clip pockets, RESET/BOOT
#          pinholes, alignment lip, bosses with M3 heat-set inserts (M3 screws come up
#          through the floor)
#
# Layout (top view, user at the bottom):
#
#             +--------------+
#        USB= | [ Feather ]  |=HDMI     back section is board length + thin side walls,
#   +---------+              +------+   centred behind the keys
#   | [k1]  [k2]  [k3]  ...  [kN]   |
#   +-------------------------------+
#
# Side view: the lid slopes down toward the user; the back (over the board) is taller.
#
# The board sits fully inside the back section. The receptacle shells overhang the
# PCB edge into the (thinner) side walls, through slots that are open at the top (so
# the board drops straight in) and sized for the cable's plug housing (so the plug
# goes all the way in). The lid closes the top of each slot.
#
# Printing without supports:
#   tray — upright as modelled. Each screw counterbore ends in a one-layer bridge over
#          the clearance hole (SACRIFICIAL_LAYER); push the screw through it.
#          No foot recesses: stick bumpers to the flat bottom.
#   lid  — exported top-face down; bosses and lip lean TILT_DEG, which prints fine.
#
# Board coordinates come from Adafruit's Eagle files (Adafruit-Feather-RP2040-DVI-PCB).
# Connector heights are NOT in those files: measure yours and adjust USB_H / HDMI_H.
#
# Run inside FreeCAD (GUI or freecadcmd):
#   p = "case/case.py"; exec(open(p).read(), {"__file__": p})
# Exports print-ready STL + 3MF to case/export/.

import math
import os
import sys
import FreeCAD as App
import Part

HERE = os.path.dirname(os.path.abspath(__file__))
sys.path.insert(0, HERE)
import cadlib  # noqa: E402

# ---- keys -------------------------------------------------------------------
NUM_KEYS       = 4
KEY_PITCH      = 19.05
SWITCH_CUTOUT  = 14.0      # from the test coupon
CLIP_POCKET    = 15.6      # recess under the plate so the switch clips can latch
PLATE_T        = 1.5       # plate thickness at each switch (MX clips need 1.5)
SWITCH_BELOW   = 8.3       # switch housing + pins below the plate's top face
SEPARATE_PLATE = True      # switches in a separate flat plate glued under a window in the
                           # lid: keys sit LID_T lower, and both parts print without supports
PLATE_FLANGE   = 3.0       # plate overlap (glue area) around the window
KEY_WINDOW     = 19.0      # window width per key (keycap 18 + clearance)
KEY_WINDOW_R   = 1.5       # window corner radius: keycap skirt corner (1.0) + the 0.5 mm gap
KEY_WINDOW_FILLET = 0.6    # rounds the window's top edge (on the bed when printing; keep small)
PIN_D, PIN_H   = 3.0, 1.0  # locating pins on the lid underside; matching holes in the plate
PIN_CLEAR      = 0.15
WIRE_ROOM      = 1.5       # floor to the lowest switch pin
SIDE_MARGIN    = 6.5       # inner wall to first/last key cell (keeps the front bosses clear of the key window)
KEY_Y_MARGIN   = 5.5   # inner wall to key cell, front and back (keys centred in the front section)
TILT_DEG       = 8.0       # lid angle, rising toward the back (0 = flat)

# ---- shell ------------------------------------------------------------------
WALL           = 2.4
FLOOR          = 3.0
LID_T          = 3.0
KEY_SINK       = LID_T if SEPARATE_PLATE else 0.0   # switch plate top below the lid surface
CORNER_R       = 3.0
LID_EDGE_R     = 1.2       # fillet on the lid's top outer edge (on the bed when printing; keep small)
LIP_H          = 2.0       # alignment lip on the lid, drops inside the walls
LIP_T          = 1.2
LIP_CLEAR      = 0.25
PORT_WALL      = 1.6       # side walls of the back section (the port walls)
PORT_CLEAR     = 0.25      # hole around each receptacle, each side
ABOVE_PORT     = 2.0       # wall material above the taller port hole

# ---- Feather RP2040 DVI (board coordinates, mm, origin = USB-C end, header JP1 side)
PCB_L, PCB_W, PCB_T = 50.8, 22.86, 1.6
PCB_HOLES      = [(2.54, 2.54), (2.54, 20.32), (48.26, 1.905), (48.26, 20.955)]
BOARD_CLEAR    = 0.3       # PCB to walls
STANDOFF_H     = 3.0       # gap under the board for untrimmed solder joints / wire ends
STANDOFF_D     = 6.0
M25_INSERT_D   = 3.2       # hole for an M2.5 x 4 x 3.5 OD heat-set insert
M25_INSERT_L   = 5.0       # hole depth: insert + screw tip; fits an M2.5 x 6 screw
RESET_XY       = (9.525, 5.08)    # SW1 -> RUN
BOOT_XY        = (15.875, 5.08)   # SW2 -> GPIO7 (readable as a button)
# RST/BOOT plunger buttons: a printed pin rests on each board button. It runs perpendicular
# to the lid (so its top sits flush and prints flat) through a rounded-rectangle hole (so
# it can't turn and its letter stays upright). A collar rides in a pocket in the lid's underside,
# closed by a tab on the switch plate: it limits travel down (the press) and up. A sleeve
# under the tab guides the tip, whose end is cut level so it sits flat on the button.
# Needs SEPARATE_PLATE.
BUTTONS        = True
BUTTON_LETTERS = ("R", "B")   # inlaid on the pin tops (RST, BOOT)
LETTER_H       = 3.76      # same size and weight as the keycap legends (they print cleanly)
LETTER_FONT    = "ARIALNB.TTF"
LETTER_BOLD    = 0.12      # strokes grown this much each side, as on the keycaps
RST_BOOT_TEXT  = False        # "RST"/"BOOT" text on the lid next to the buttons
BTN_H          = 2.6       # board button height above the PCB (measured)
BTN_BODY       = (4.2, 3.05)  # board button footprint (for clash checks)
BTN_TRAVEL     = 0.4       # press travel before the collar lands on the plate tab
PLUNGER_W      = 4.4       # pin top, left-right (what you press)
PLUNGER_L      = 5.0       # pin top, front-back
PLUNGER_R      = 0.8       # pin top corner radius
PLUNGER_CLEAR  = 0.25      # each side, in the lid hole
PLUNGER_RECESS = 0.0       # pin top below the lid surface (0 = flush)
BTN_FILLET     = 0.3       # rounds the pin tops and the top edges of their holes
COLLAR_GROW    = (0.3, 0.8)  # collar beyond the shaft: left-right (the pins are close), front-back
COLLAR_T       = 0.6       # flat part of the collar; above it a taper to the shaft
TIP_D          = 2.8       # pin below the collar, onto the button
TIP_CLEAR      = 0.3       # radial, in the tab hole and sleeve (must slide freely)
SLEEVE_WALL    = 1.0
SLEEVE_GAP     = 1.2       # sleeve end above the board button
LID_SKIN       = 1.0       # lid material above the collar pocket (sets how far a pin can lift)
POCKET_CLEAR   = 0.25      # radial, around the collar
PINHOLE_D      = PLUNGER_L + 2 * PLUNGER_CLEAR if BUTTONS else 2.2   # front-back hole size
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

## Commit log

2026-10-05 HDMI-DDC input switch: firmware, web page and case
    A desk box with MX keys that switches a monitor's input over DDC/CI from an
    Adafruit Feather RP2040 DVI on a spare HDMI port.
    - Firmware (PlatformIO, arduino-pico): DDC/CI input select with presets
    (LG UltraGear VCP 0xF4, standard MCCS), keys from flash config, PicoDVI
    info screen, JSON serial protocol.
    - Web page: build guide, Web Serial configurator and firmware installer.
    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
    [case-buttons.3mf, case-lid.3mf, case-plate.3mf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]
2026-10-05 CI: update actions to Node 24 versions, pin runner to ubuntu-24.04
    Clears the Node.js 20 deprecation warning (checkout v7, setup-python v7,
    cache v6, upload-artifact v7, download-artifact v8, configure-pages v6,
    upload-pages-artifact v5, deploy-pages v5) and keeps release builds off the
    moving ubuntu-latest image.
2026-10-07 Info screen: video only on demand, restyled with Noto Sans
    - Fix: the monitor jumped to the switch's HDMI port whenever the active input
    slept, because the port always carried a picture. The DVI output drivers are
    now switched off (output-enable override, keeping PicoDVI's pair inversion)
    except while the info screen is in use: the switch's own key turns it on,
    any other input turns it off, 5-minute timeout. DDC is unaffected, and the
    monitor can go to standby.
    - Info screen redrawn in 640x480 1-bit graphics: title with version pill,
    framed Keys / Monitor / Tips panels, current input highlighted, set-up
    address and uptime in the footer.
    - Fonts: Noto Sans (OFL) rendered to GFX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
    [gfxfont.py, protocol.cpp]
